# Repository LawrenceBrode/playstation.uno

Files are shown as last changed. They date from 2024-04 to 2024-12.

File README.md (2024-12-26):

https://drive.google.com/file/d/1QOa1Ci1hhO2Aoj20PWo5wt0c2_igYG66/view?usp=sharing
this is a tiff file with multilayer drawings of the traces, i used Sketchbook, using gimp you could need a plugin to view the layers. Thats with the update folder are all the work i did :)

# PS1-SANDPAPER
Sony's Playstation 1 console reverse engineering

CONSOLE: PLAYSTATION 1
MODEL NO. SCPH-7502  PAL
MADE IN JAPAN

<br>
Da tradurre:
<br>
<br>
In questo progetto si punta a fare un ingegneria inversa della famosissima console SONY, la Playstation 1.
Malgrado la vasta quantità di informazioni, software e homebrew per la console, in rete non sono riuscito a trovare uno schema dettagliato della scheda madre.
Questo fatto non mi stupisce nemmeno più di troppo tenendo conto che sarebbero documenti interni, e confidenziali, di cui Sony non ha mai avuto il minimo interesse da condividere.
<br><br>
Quello che mi ha incentivato a intraprendere questo curioso e alquanto arduo progetto è il fatto che il layout della scheda madre sia su solamente due strati di rame, top layer & bottom layer, questo è uno dei più semplici tipi di circuiti stampati in quando i due strati di rame sono esposti sulle corrispettive e opposte facce. 
<br><br>
Esempio: Le console moderne, ma come anche i computer usano circuiti stampati a 6-12+ strati di rame, rendendo ancora più complicato un lavoro di ingegneria inversa, dovendo appunto scartavetrare gli strati uno per uno e facendo una scanssione.
<br><br>
Quindi data la semplicità di layout della scheda madre e l'enorme quantità di informazioni sul hardware della console, sono abbastanza fiducioso di riuscire a creare un clone della scheda madre originale (MODEL NO. SCPH-7502), sempre a due strati copindo il layout originale. Inoltre sono curioso di vedere come si protrebbe avviare il sistema usando il minimo indispendabile, quindi rimuovendo alcuni chip come quello del CD DRIVER e quelli dell'AUDIO.
<br><br>
Il mio lavoro è cominciato con una PS1 non funzionante, la cui ho smontato e rimosso accuratamente i vari integrati con una HEAT GUN impostata a 450°C, operazione semplice si ma da fare con determinazione in quanto esporre la scheda madre (ricordiamoci che è sempre fibra di vetro) o le componenti per troppo tempo al calore estremo le danneggia, creando anche bolle sulla scheda.
<br><br>
Rimossi gli IC sono passato a rimuovere le porte AV, SERIAL I/O e PARALLEL I/O, dopo ho proceduto in modo più superficiale a rimuove qualsiasi componente SMD dalla scheda.
<br><br>
A scheda "pulita" ho spalmato uno strato di flussante su tutta la scheda per ripristinare i contatti in stagno e pulire la scheda dalle sbavature di stagno.
<br><br>
Infine ho lavato la scheda sotto l'acqua corrente e l'ho asciugare, procedendo a effettuare una scansione a 300 DPI con lo scanner.
<br><br>
Fatto ciò ho iniziato la parte più complicata, quella di sabbiatura della scheda, l'obiettivo è di rimuovere la Solder Mask (vernice verde solito delle PCB che evita l'ossidazione delle piste di rame), ho usato una spugna di cartavetro a grana fine, di seguito si vedono i due lavori, ancora in corso.
<br><br>

topLayerSolderMaskEdited

topLayerCopperEdited

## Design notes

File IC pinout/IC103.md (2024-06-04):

#### CPU Pinouts (IC103)

| Pin | Name | Pin | Name | Pin | Name | Pin | Name |
| --: | :--- | --: | :--- | --: | :--- | --: | :--- |
| 1 | `VDD` |  53 | `VDD` | 105 | `VDD` | 157 | `VDD` |
| 2 | `VDD` |  54 | `VDD` | 106 | `VDD` | 158 | `VDD` |
| 3 | `CRYSTALN`  |  55 | `RAM.A11` | 107 | `SBUS.D0`  | 159 | `TIMER1.CLK` |
| 4 | `CRYSTALP`  |  56 | `RAM.A10` | 108 | `SBUS.D1`  | 160 | `TIMER0.CLK` |
| 5 | `RAM.D31` |  57 | `RAM.A9` | 109 | `SBUS.D2`  | 161 | `GPU.D0` |
| 6 | `RAM.D30` |  58 | `RAM.A8` | 110 | `SBUS.D3`  | 162 | `GPU.D1` |
| 7 | `RAM.D29` |  59 | `RAM.A7` | 111 | `SBUS.D4`  | 163 | `GPU.D2` |
| 8 | `RAM.D28` |  60 | `RAM.A6` | 112 | `SBUS.D5`  | 164 | `GPU.D3` |
| 9 | `RAM.D27` |  61 | `RAM.A5` | 113 | `SBUS.D6`  | 165 | `GPU.D4` |
|  10 | `RAM.D26` |  62 | `RAM.A4` | 114 | `SBUS.D7`  | 166 | `GPU.D5` |
|  11 | `RAM.D25` |  63 | `RAM.A3` | 115 | `SBUS.D8`  | 167 | `GPU.D6` |
|  12 | `RAM.D24` |  64 | `RAM.A2` | 116 | `SBUS.D9`  | 168 | `GPU.D7` |
|  13 | `RAM.D23` |  65 | `GND` | 117 | `GND` | 169 | `GPU.D8` |
|  14 | `VDD` |  66 | `VDD` | 118 | `VDD` | 170 | `GND` |
|  15 | `GND` |  67 | `RAM.A1` | 119 | `SBUS.D10` | 171 | `VDD` |
|  16 | `RAM.D22` |  68 | `RAM.A0` | 120 | `SBUS.D11` | 172 | `GPU.D9` |
|  17 | `RAM.D21` |  69 | `/RC_NET` | 121 | `SBUS.D12` | 173 | `GPU.D10` |
|  18 | `RAM.D20` |  70 | `SIO1./RTS` | 122 | `SBUS.D13` | 174 | `GPU.D11` |
|  19 | `RAM.D19` |  71 | `SIO1./CTS` | 123 | `SBUS.D14` | 175 | `GPU.D12` |
|  20 | `RAM.D18` |  72 | `SIO1./DTR` | 124 | `SBUS.D15` | 176 | `GPU.D13` |
|  21 | `RAM.D17` |  73 | `SIO1./DSR` | 125 | `SBUS.A0`  | 177 | `GPU.D14` |
|  22 | `RAM.D16` |  74 | `SIO1.TX` | 126 | `SBUS.A1`  | 178 | `GPU.D15` |
|  23 | `RAM.D15` |  75 | `SIO1.RX` | 127 | `SBUS.A2`  | 179 | `GPU.D16` |
|  24 | `RAM.D14` |  76 | `/EXT_RESET` | 128 | `SBUS.A3`  | 180 | `GPU.D17` |
|  25 | `RAM.D13` |  77 | `SIO0./DTR2` | 129 | `SBUS.A4`  | 181 | `GPU.D18` |
|  26 | `VDD` |  78 | `GND` | 130 | `GND` | 182 | `GND` |
|  27 | `GND` |  79 | `VDD` | 131 | `VDD` | 183 | `VDD` |
|  28 | `RAM.D12` |  80 | `SIO0./DTR1` | 132 | `SBUS.A5`  | 184 | `GPU.D19` |
|  29 | `RAM.D11` |  81 | `SIO0./SCK` | 133 | `SBUS.A6`  | 185 | `GPU.D20` |
|  30 | `RAM.D10` |  82 | `SIO0./DSR` | 134 | `SBUS.A7`  | 186 | `GPU.D21` |
|  31 | `RAM.D9` |  83 | `SIO0.TX` | 135 | `SBUS.A8`  | 187 | `GPU.D22` |
|  32 | `RAM.D8` |  84 | `SIO0.RX` | 136 | `SBUS.A9`  | 188 | `GPU.D23` |
|  33 | `RAM.D7` |  85 | `SBUS.DACK5_PIO`  | 137 | `SBUS.A10` | 189 | `GPU.D24` |
|  34 | `RAM.D6` |  86 | `SBUS.DREQ5_PIO`  | 138 | `SBUS.A11` | 190 | `GPU.D25` |
|  35 | `RAM.D5` |  87 | `SBUS.DACK4_SPU`  | 139 | `SBUS.A12` | 191 | `GPU.D26` |
|  36 | `RAM.D4` |  88 | `SBUS.DREQ4_SPU`  | 140 | `SBUS.A13` | 192 | `GPU.D27` |
|  37 | `RAM.D3` |  89 | `/IRQ10_PIO` | 141 | `SBUS.A14` | 193 | `GPU.D28` |
|  38 | `VDD` |  90 | `/IRQ9_SPU` | 142 | `SBUS.A15` | 194 | `GPU.D29` |
|  39 | `GND` |  91 | `GND` | 143 | `GND` | 195 | `GND` |
|  40 | `RAM.D2` |  92 | `VDD` | 144 | `VDD` | 196 | `VDD` |
|  41 | `RAM.D1` |  93 | `/CSHTST` | 145 | `SBUS.A16` | 197 | `GPU.D30` |
|  42 | `RAM.D0` |  94 | `/IRQ2_CDROM` | 146 | `SBUS.A17` | 198 | `GPU.D31` |
|  43 | `RAM./WE` |  95 | `SBUS./CS5_CDROM` | 147 | `SBUS.A18` | 199 | `/IRQ0` |
|  44 | `RAM./RAS1` |  96 | `SBUS./CS4_SPU` | 148 | `SBUS.A19` | 200 | `GPU.DREQ2`  |
|  45 | `RAM./RAS0` |  97 | `SBUS./CS2_BIOS`  | 149 | `SBUS.A20` | 201 | `SYSCK0` |
|  46 | `RAM./CAS3` |  98 | `SBUS./CS0_EXP1`  | 150 | `SBUS.A21` | 202 | `GPU.DACK2`  |
|  47 | `RAM./CAS2` |  99 | `SBUS./WR1` | 151 | `SBUS.A22` | 203 | `GPU./WR` |
|  48 | `RAM./CAS1` | 100 | `SBUS./WR0` | 152 | `SBUS.A23` | 204 | `GPU./RD` |
|  49 | `RAM./CAS0` | 101 | `SBUS./RD` | 153 | `GPU.A0` | 205 | `GPU./CS7` |
|  50 | `VDD` | 102 | `/IRQ1_GPU` | 154 | `SYSCK1` | 206 | `DSYSCK0` |
|  51 | `GND` | 103 | `GND` | 155 | `GND` | 207 | `GND` |
|  52 | `GND` | 104 | `GND` | 156 | `GND` | 208 | `GND` |

Pin5-68 = Main RAM bus. Pin 95-152 = System bus. Pin 102,153,159-206 = Video
bus.<br/>

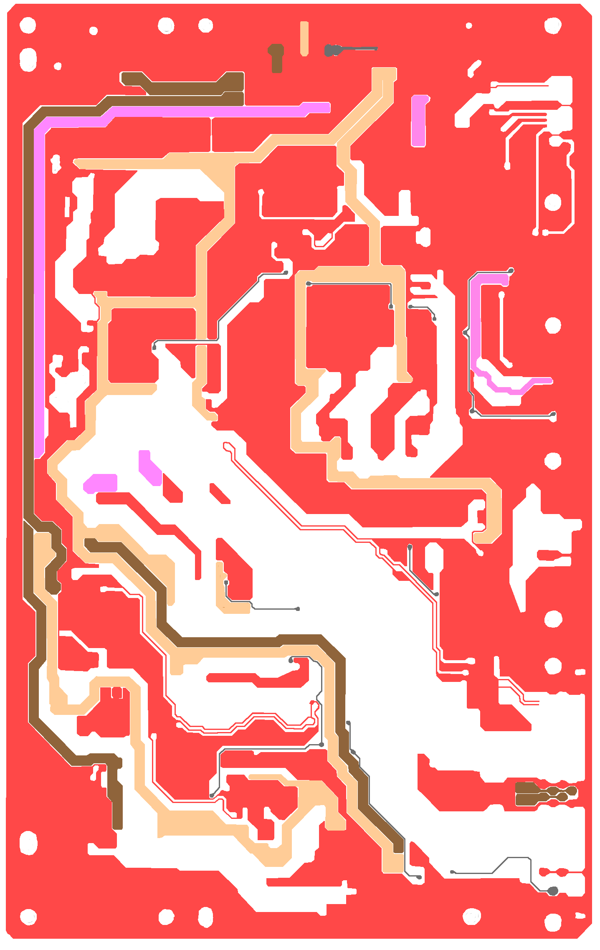
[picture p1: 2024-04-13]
PS1 Motherboard/bottomLayerPowerConnection.png

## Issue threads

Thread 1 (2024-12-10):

Schematics and boardlayout, SCPH-100_5th-Edition

CodeAsm, 2024-12-10:
For those curious if Sony had service manuals:
https://www.psxdev.net/downloads/SCPH-100_5th-Edition.pdf

but ill say this, sanding down and making sure any connection you see and measure are actually truth with what youve found in the real world is probably worth way more. especially if you need workable schematics and such to redesign it later in another format. Still making the work you put in this worthwhile.

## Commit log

2024-03-17 Add files via upload
    added CPU (IC103) | GPU (IC203) | SPU (IC732) package datasheet (smd footprint)
2024-03-17 HIGH QUALITY MOTHERBOARD SCANS
    edited and original pcb (sanded and not) scans
2024-12-26 files for parts/symbols/footprints and ps1 schematics
    [IC102.schdoc, IC103.schdoc, IC106.schdoc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]
2024-12-26 simple png of traces
